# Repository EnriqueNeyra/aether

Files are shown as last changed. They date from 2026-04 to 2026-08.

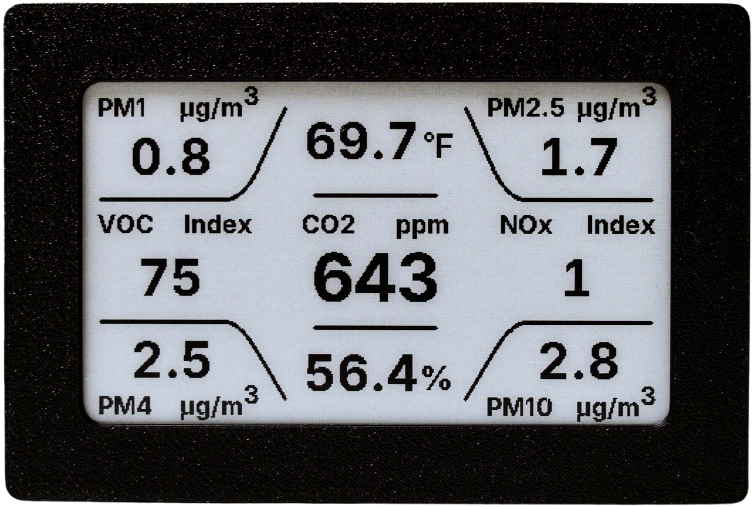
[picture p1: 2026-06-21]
www/assets/aether-device-black.png

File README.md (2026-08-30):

# Aether

A6700222

### Aether is a comprehensive air quality monitor by [**Syntropy Labs**](https://syntropylabs.io/products/aether-air-quality-monitor) built around an ESP32-C3, a Sensirion SEN66 sensor, and a 3.7" e-paper display. It measures **CO2, Temperature, Humidity, PM1.0, PM2.5, PM4.0, PM10, VOC index, and NOx index**, and exposes those readings on-device, on the local network, and through Home Assistant.

## Repo Guide

| Path | Contents |
| --- | --- |
| `firmware/` | ESPHome configuration, custom components, web UI sources, and display code |
| `hardware/pcb/` | KiCad PCB project |
| `hardware/manufacturing/` | PCB manufacturing outputs, BOM, and centroid files |
| `hardware/datasheets/` | Reference datasheets used during hardware design |
| `enclosure/` | SolidWorks enclosure and assembly files |
| `manifests/` | Firmware manifests for OTA and WebUSB |
| `www/` | The combined WebUSB flasher and Quick Start Guide site |

## Contents

- [Features](#features)
- [Hardware](#hardware)
- [Assembly](#assembly)
- [Firmware Setup](#firmware-setup)
  - [Flashing firmware onto a device](#flashing-firmware-onto-a-device)
  - [Firmware development](#firmware-development)
- [Using Aether](#using-aether)
  - [Normal operation](#normal-operation)
  - [Wi-Fi setup and behavior](#wi-fi-setup-and-behavior)
  - [Side button behavior](#side-button-behavior)
  - [Local web UI](#local-web-ui)
  - [Home Assistant & ESPHome API](#home-assistant--esphome-api)
  - [Updates](#pdates)
- [License](#license)

## Features

- Measures CO2, Temperature, Humidity, PM1.0, PM2.5, PM4.0, PM10, VOC index, and NOx index using the **Sensirion SEN66**
- Displays live readings on a **416x240 3.7" e-paper panel**
- Serves a **local web dashboard** from the device itself
- Supports **ESPHome / Home Assistant** integration
- Supports **USB factory flashing**, **firmware recovery**, and **OTA updates**
- Fully local, and can run **with or without Wi-Fi**

## Hardware

To build one Aether unit, the following core parts are needed:

| Part | Link |
| --- | --- |
| **Aether PCB** | [Syntropy Labs Store](https://syntropylabs.io/products/aether-air-quality-monitor-custom-pcb) (PCB files available in [`hardware/`](https://github.com/EnriqueNeyra/aether/tree/main/hardware/manufacturing) folder) |
| **3.7" e-paper display module** | [Good Display](https://buy-lcd.com/products/37-inch-416x240-e-paper-black-and-white-spi-fast-refresh-electronic-eink-display-screen-esl-gdey037t03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) / [Elecrow](https://www.elecrow.com/3-7-inch-240-416-e-paper-display-black-white-e-ink-display-with-spi-communication.html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) |
| **Sensirion SEN66** air quality sensor | [Sensirion](https://sensirion.com/products/catalog/SEN66) |
| **Reverse 6-pin JST-GH cable** | [Adafruit](https://www.adafruit.com/product/5754?srsltid=AfmBOopcC6siE6KqjNqU-nj7AwIrnvlDSqnL19iwFrZ47O6lRIhqRYC8) / [AliExpress](https://www.aliexpress.us/w/wholesale-jst-gh-1.25mm-connector-6-pin-reverse.html?spm=a2g0o.detail.search.0) |
| **3D-printed enclosure parts** | [`enclosure/`](https://github.com/EnriqueNeyra/aether/tree/main/enclosure) |
| **2x M3 x 6 mm countersunk screws + nuts** | [Screws](https://amzn.to/3SKvOgg) / [Nuts](https://amzn.to/44jUIG1) |

<p align="center">A6700230</p>

### Alternative Display Compatibility

The Aether PCB implements the standard 24-pin FPC e-paper interface. While designed for the 3.7" GDEY037T03, it is hardware-compatible with many other common e-paper panels (e.g., those using SSD1680, UC8151D, and IL0373 driver ICs). **Please note that these alternative displays have not yet been tested or confirmed to work with this device.**

If you choose to use an alternative display, you will need to:
1. **Update the firmware** to instantiate the correct `GxEPD2` display driver class.
2. **Modify the enclosure design** to physically fit the new panel dimensions.

For specific supported ICs and detailed firmware instructions, see [display-compatibility.md](display-compatibility.md).

## Assembly

High-level assembly flow:

### 1. Press-fit the SEN66 into the enclosure body.

<p align="center">Insert_SEN66_into_Enclosure</p>

### 2. Connect the e-paper display to the PCB with the FPC connector.

<p align="center">Connect_ePaper_to_PCB</p>

### 3. Press-fit the PCB into the enclosure body.

<p align="center">Insert_PCB_into_Enclosure</p>

### 4. Connect 6-pin JST GH Cable.

<p align="center">Connect_JST_Cable</p>

### 5. Bring display over in position above the PCB.

<p align="center">Display_Placement_1</p>
<p align="center">Display_Placement_2</p>

### 6. Attach the display cover.

<p align="center">Attach_Display_Cover</p>

### 7. Secure the assembly from the bottom with the two M3 fasteners.

<p align="center">Secure_With_M3_Screws</p>

## Firmware Setup
_Any Aether devices purchased through [**Syntropy Labs**](https://syntropylabs.io/) are pre-flashed with device firmware and fully tested_

### Flashing firmware onto a device

#### For a new board or a device that needs recovery:

1. Connect Aether to your computer over USB.
2. Open the [Aether WebUSB flashing tool](https://aether.syntropylabs.io/).
3. Choose **Factory flash (recommended)** for first-time setup or full recovery.
4. Keep the page open until flashing is complete.
5. Let the device boot.

#### For a device that is already set up and just needs newer firmware:

1. Connect the device over USB and open the same flashing page.
2. Choose **Update firmware (OTA)** if you want to preserve the current device settings.

_Note: The flashing page in `www/` is built around **ESP Web Tools / WebUSB** and is intended to work best in **Chrome or Edge**._

### Firmware development

If you are working on the ESPHome firmware:

```sh
git clone https://github.com/EnriqueNeyra/aether.git
cd "aether/firmware"
```

```sh
cd firmware
esphome config aether.yaml
esphome compile aether.yaml
esphome run aether.yaml
```

## Using Aether

### Normal operation

Once powered, Aether reads the SEN66 and refreshes both the on-device display and the local web dashboard. Temperature can be shown in either **Fahrenheit** or **Celsius**.

### Wi-Fi setup and behavior

On boot, Aether will expose a temporary setup access point so you can connect it to Wi-Fi through the captive portal flow. The network will appear as **aether-XXXXX**. 

<p align="center">aether-access-point</p> 

- If you want **local web UI access**, **network-based ota updates**, or **Home Assistant integration**, connect the device to Wi-Fi during setup.
- If you do **not** configure Wi-Fi, the device will still work as a standalone monitor **fully offline**.

Once connected to the access point, you will automatically be redirected to the captive portal. Select your network and enter the password to connect. Once connected to Wi-Fi, the device also hosts its [local web UI](#local-web-ui) at **aether-XXXXXX.local** or the **device's local IP**.

### Side button behavior

The side / boot button supports multiple actions:

- **Short press (tap, under 1 second):** toggles between the normal dashboard and the info screen
- **Long press (hold ~3 seconds) from the normal screen:** enters factory reset confirmation
- **Long press (hold ~3 seconds) again on the reset screen:** confirms the factory reset flow

### Local web UI

When Aether is on your network, it serves a local browser-based dashboard directly from the device. That UI includes:

- A live environment view for sensor readings
- Temperature unit switching
- Firmware version and update status
- A way to trigger firmware updates from the device UI

### Home Assistant & ESPHome API

Because Aether runs ESPHome, it features a native API over Wi-Fi. This allows for:

- **Automatic Home Assistant Integration:** Aether will automatically appear in Home Assistant integrations dashboard once connected to your network. It securely exposes all 9 sensor metrics (CO2, Temp, PM2.5, etc).

<p align="center">
  <a href="https://my.home-assistant.io/redirect/integrations/">
    
  </a>
</p>

- **Custom Integrations:** You can integrate Aether into your own software or scripts using its local HTTP API. Exposed endpoints include:
  - `GET /api/state` - Returns a JSON object with all current sensor metrics and device status.
  - `POST /api/temp_unit?unit=C|F` - Changes the preferred temperature unit.
  - `POST /api/perform_update` - Triggers the device to immediately begin downloading and installing the latest firmware update over HTTP (if one is available).

### Updates

Aether supports more than one update path:

- **Local USB flashing** through the [WebUSB flashing tool](https://aether.syntropylabs.io/) (source located in `www/`)
- **In-device update flow** through the local web UI
- **Home Assistant** when the device is online

Use the USB flashing page for first-time setup and recovery. Use the local web UI for routine updates on devices that are already deployed.

## License

This project (hardware, design files, and firmware) is licensed under the
[Creative Commons Attribution-NonCommercial-ShareAlike 4.0 International License](http://creativecommons.org/licenses/by-nc-sa/4.0/).



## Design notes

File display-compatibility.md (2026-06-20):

# E-Paper Display Compatibility

The Aether project is designed around the **GDEY037T03** (3.7" 416x240) black-and-white e-paper display, which uses the **UC8253** driver IC. 

However, both the hardware (PCB) and software (firmware) are highly adaptable to other e-paper displays.

## Hardware Compatibility (The 24-Pin Standard)

The Aether PCB implements the **standard 24-pin FPC (0.5mm pitch) e-paper interface**. This is the industry standard for small-to-medium raw e-ink panels from manufacturers like Good Display and Waveshare.

Because of this standard, the custom PCB is **hardware-compatible** with a wide variety of other e-paper driver ICs. The external boost circuit on the board (MOSFET, inductor, and schottky diode) that generates the panel's internal driving voltages is universally shared across these controller families.

**Note: While the hardware standard and firmware library theoretically support the ICs listed below, they have not yet been explicitly tested or confirmed to work with the Aether device.**

Other common e-paper driver ICs that use this exact same 24-pin hardware footprint include:

*   **Solomon Systech ICs:**
    *   **SSD1680** (Very common on 2.13", 2.66", and 2.9" panels)
    *   **SSD1677**
    *   **SSD1619**
*   **UltraChip ICs** (Same manufacturer as the UC8253):
    *   **UC8151D / UC8151C** (Common on 1.54" and 2.9" panels)
    *   **UC8159** (Used for 7-color ACeP displays)
    *   **UC8179** (Common on 4.2" panels)
*   **Ilitek ICs:**
    *   **IL0373 / IL0398** (Frequently used for 3-color Black/White/Red panels and some larger B/W screens)

## Software Compatibility (GxEPD2)

While the physical PCB footprint is compatible with all of the ICs listed above, **driver ICs are not natively software-compatible with one another**. Every IC has its own specific command set, memory mapping, and timing waveforms required to drive the e-ink microcapsules.

Fortunately, the Aether firmware uses the `GxEPD2` library, which is the most comprehensive e-paper driver library available for the ESP32. **`GxEPD2` supports all of the ICs listed above.**

### How to Switch Displays in Firmware

To support a display with a different IC, you do not need to rewrite any graphics logic. You only need to update the display class instantiation in the firmware.

Open `firmware/components/aether_epaper/aether_epaper.h`. Currently, it initializes the UC8253:

```cpp
// GDEY037T03 (416x240) using UC8253
static GxEPD2_BW<GxEPD2_370_GDEY037T03, GxEPD2_370_GDEY037T03::HEIGHT>
    display(GxEPD2_370_GDEY037T03(EPD_CS, EPD_DC, EPD_RST, EPD_BUSY));
```

If you were to swap the display to a 2.9" panel using the **SSD1680** IC (e.g., part number GDEY029T94), you would look up its class in the `GxEPD2` documentation and update those lines:

```cpp
// GDEY029T94 (296x128) using SSD1680
static GxEPD2_BW<GxEPD2_290_GDEY029T94, GxEPD2_290_GDEY029T94::HEIGHT>
    display(GxEPD2_290_GDEY029T94(EPD_CS, EPD_DC, EPD_RST, EPD_BUSY));
```

Because `GxEPD2` extends the standard Adafruit GFX library, all existing drawing commands (`display.print`, `display.drawRect`, etc.) will continue to work perfectly. 

*(Note: Depending on the resolution of the new display, you may need to adjust the UI layout coordinates in `aether_epaper_layout.h` to fit the new screen dimensions).*

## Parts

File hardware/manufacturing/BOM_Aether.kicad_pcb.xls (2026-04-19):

Designator | Quantity | Value | Footprint | Package | MPN | DNP | Mount_Type | Description | LCSC Part | Supplier | Manufacturer | MF | MAXIMUM_PACKAGE_HEIGHT | Price | Check_prices | STANDARD | PARTREV | SnapEDA_Link | MP | Description_1 | Availability | MANUFACTURER
C1 | 1 | 10uf/25V | C_0603_1608Metric |  |  |  | smt | Unpolarized capacitor
C10, C11, C12, C13, C14, C16, C19, C20, C8 | 9 | 4.7uf/25V | C_0603_1608Metric |  |  |  | smt | Unpolarized capacitor
C15, C17, C18, C21, C4 | 5 | 1uf/50V | C_0603_1608Metric |  |  |  | smt | Unpolarized capacitor
C2, C3, C5, C9 | 4 | 0.1uf/50V | C_0603_1608Metric |  |  |  | smt | Unpolarized capacitor
C6, C7 | 2 | 22uf/10V | C_0603_1608Metric |  |  |  | smt | Unpolarized capacitor
CN1 | 1 | SH-GH1.25-6PWB | SW-SMD_SH-GH1.25-6PWB |  |  |  | smt | Connector Header 6 position 1.25mm Pitch 1A Surface Mount, Right Angle -25℃~+85℃ | C42372473 | LCSC | SHOU HAN
D1 | 1 | 1N5819WS | D_SOD-323 |  |  |  | smt | 40V 600mV@1A 1A SOD-323 Schottky Barrier Diodes, SOD-323
D2, D3, D4 | 3 | LESD5D5.0CT1G_C5274290 | SOD-523_L1.2-W0.8-LS1.6-BI |  |  |  | smt | 18.6V 150W@8/20us 5V SOD-523 TVS Diodes RoHS | C5274290 | LCSC | LRC
D5, D6, D7 | 3 | MBR0530 | D_SOD-123 |  |  |  | smt | 30V 0.5A Schottky Power Rectifier Diode, SOD-123
FPC1 | 1 | FPC-05FB-24PH20 | FPC-SMD_24P-P0.50_FPC-05FB-24PH20 |  |  |  | smt | FFC/FPC Connector 24 Position 0.5mm Pitch Double-Sided Contacts, Top and Bottom Entry Surface Mount, Right Angle -25℃~+85℃ | C2856831 | LCSC | XUNPU
L1 | 1 | NR3015S2R2MT | IND-SMD_L3.0-W3.0_NR3010 |  |  |  | smt | 1.6A 2.2uH 64mΩ 1.6A ±20% SMD,3x3mm Fixed Inductors RoHS | C42370319 | LCSC | Magnetsyc
L2 | 1 | 10uH/1A | L_1210_3225Metric |  |  |  | smt | Inductor
Q1 | 1 | Si1308EDL | SOT-323_SC-70 |  |  |  | smt | 30V Vds, 1.4A Id, N-Channel MOSFET, SC-70
R1, R10, R12, R2, R3, R6, R9 | 7 | 10k | R_0402_1005Metric |  |  |  | smt | Resistor
R11 | 1 | 3 | R_0402_1005Metric |  |  |  | smt | Resistor
R13 | 1 | 0.47 | R_0402_1005Metric |  |  |  | smt | Resistor
R4, R5 | 2 | 5.1k | R_0402_1005Metric |  |  |  | smt | Resistor
R7 | 1 | 453k | R_0603_1608Metric |  |  |  | smt | Resistor
R8 | 1 | 100k | R_0603_1608Metric |  |  |  | smt | Resistor
SW2 | 1 | TS-1088-AR02016 | SW-SMD_L3.9-W3.0-P4.45 |  |  |  | smt | Tactile Switch SPST 160gf 2mm SMD (SMT) Tab 4mm x 3mm Surface Mount | C720477 | LCSC | XUNPU
SW3 | 1 | TS36XL-6.0 180GF 072 | SW-TH_SHOU-HAN_TS36XL-6.0 |  |  |  | tht | Tactile Switch SPST 180gf 6mm SMD (SMT) Tab 4.55mm Surface Mount, Right Angle | C2859427 | LCSC | SHOU HAN
TP1 | 1 | TestPoint | TestPoint_Pad_D1.5mm |  |  | Yes | smt | test point
TP2 | 1 | TestPoint | TestPoint_Pad_D1.5mm |  |  | Yes | smt | test point
TP3 | 1 | TestPoint | TestPoint_Pad_D1.5mm |  |  | Yes | smt | test point
TP4 | 1 | TestPoint | TestPoint_Pad_D1.5mm |  |  | Yes | smt | test point
TP5 | 1 | TestPoint | TestPoint_Pad_D1.5mm |  |  | Yes | smt | test point
TP6 | 1 | TestPoint | TestPoint_Pad_D1.5mm |  |  | Yes | smt | test point
U1 | 1 | TYPE-C 16PLT-H10.0 | TYPE-C-SMD_USB4120-03-C |  |  |  | smt | USB-C (USB TYPE-C) Receptacle Connector 16 Position Surface Mount | C3151749 | LCSC | SHOU HAN
U2 | 1 | ESP32-C3-MINI-1-N4 | XCVR_ESP32-C3-MINI-1-N4 | SMD-53 Espressif Systems |  |  | smt |  |  |  |  | Espressif Systems | 2.55mm | None | https://www.snapeda.com/parts/ESP32-C3-MINI-1-N4/Espressif+Systems/view-part/?ref=eda | Manufacturer Recommendations | v1.0 | https://www.snapeda.com/parts/ESP32-C3-MINI-1-N4/Espressif+Systems/view-part/?ref=snap | ESP32-C3-MINI-1-N4 | Bluetooth, WiFi 802.11b/g/n, Bluetooth v5.0 Transceiver Module 2.412GHz ~ 2.484GHz PCB Trace Surface Mount | In Stock | Espressif Systems
U3 | 1 | TLV62569DBVR | SOT-23-5_L3.0-W1.7-P0.95-LS2.8-BR |  |  |  | smt | 1.5MHz Buck Adjustable 600mV~5.5V 2A SOT-23-5 Voltage Regulators - DC DC Switching Regulators RoHS | C141836 | LCSC | TI

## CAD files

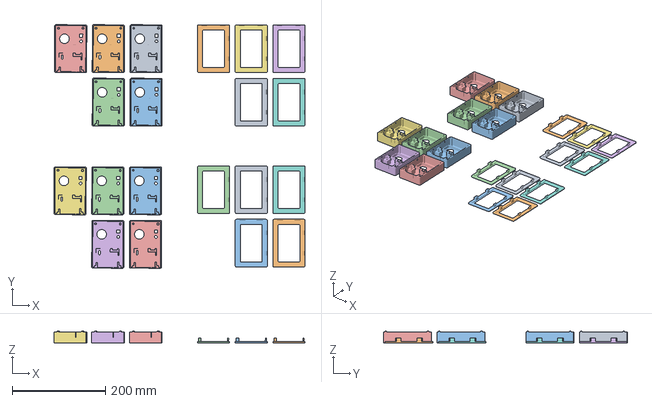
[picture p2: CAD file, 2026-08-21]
enclosure/aether_bulk_print.3mf
539.6 x 523.7 x 25.8 mm
enclosure_body.STEP x 10
display_cover.STEP x 10

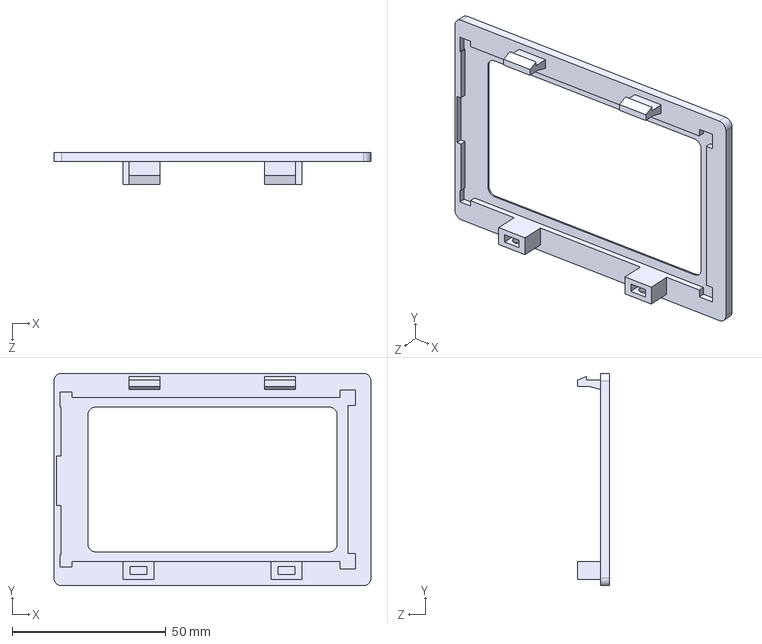
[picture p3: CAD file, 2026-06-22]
enclosure/display_cover.STEP
103.0 x 69.0 x 10.5 mm

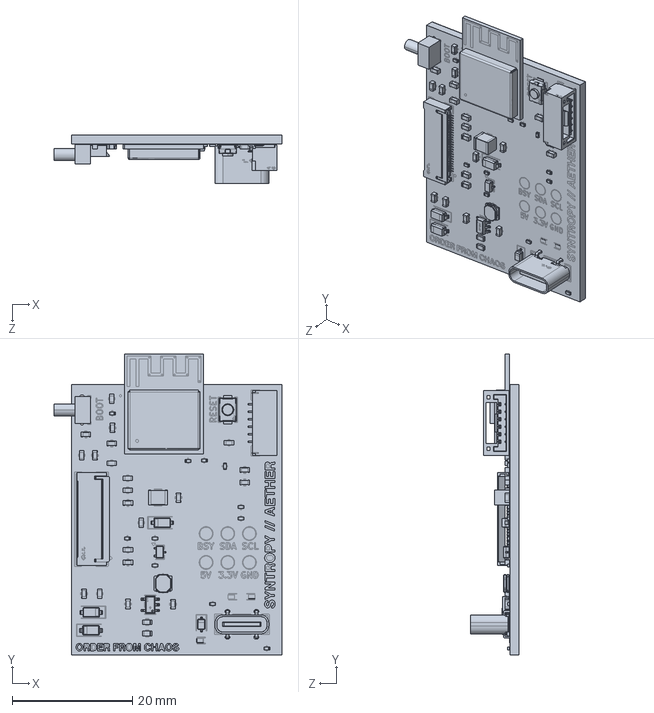
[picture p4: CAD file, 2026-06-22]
enclosure/solidworks/aether_pcb.SLDPRT
37.9 x 50.1 x 8.14 mm

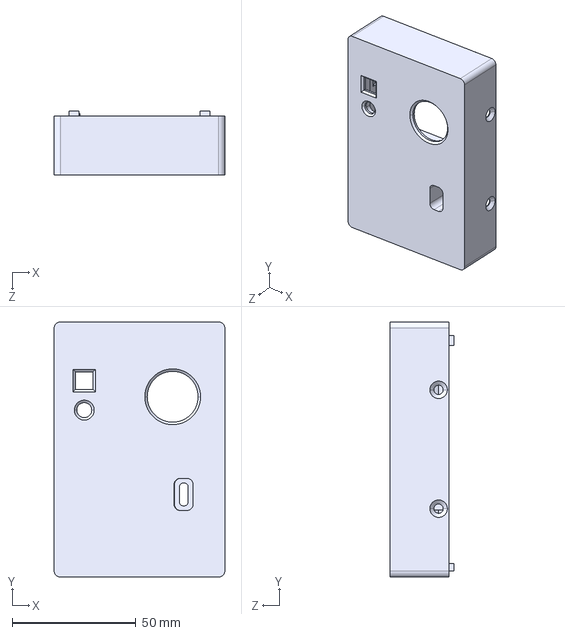
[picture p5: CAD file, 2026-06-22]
enclosure/enclosure_body.STEP
69.0 x 103.0 x 25.8 mm

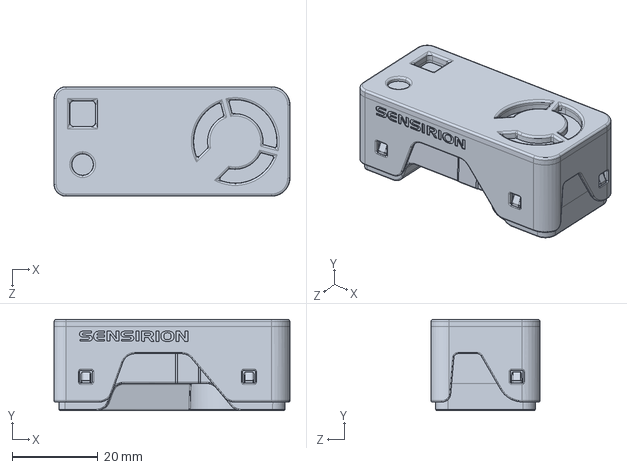
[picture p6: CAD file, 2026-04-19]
enclosure/solidworks/sen66.SLDPRT
55.2 x 21.3 x 25.6 mm

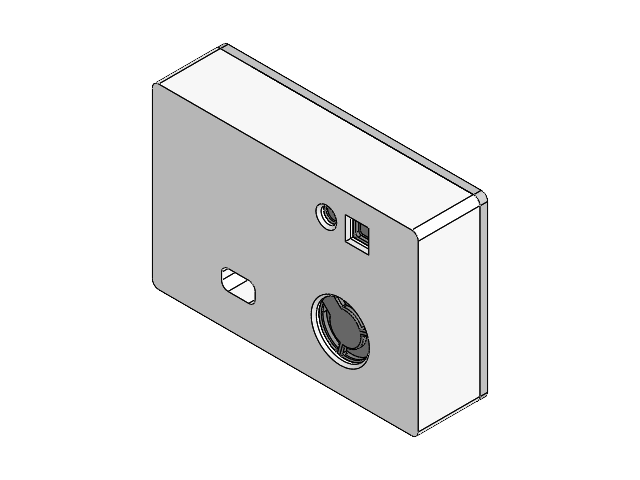
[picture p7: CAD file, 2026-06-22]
enclosure/solidworks/aether_assembly.SLDASM
aether_pcb
SEN66
Enclosure Body
Display Cover

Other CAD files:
enclosure/solidworks/display_module.SLDPRT
enclosure/solidworks/display_cover.SLDPRT
enclosure/solidworks/enclosure_body.SLDPRT

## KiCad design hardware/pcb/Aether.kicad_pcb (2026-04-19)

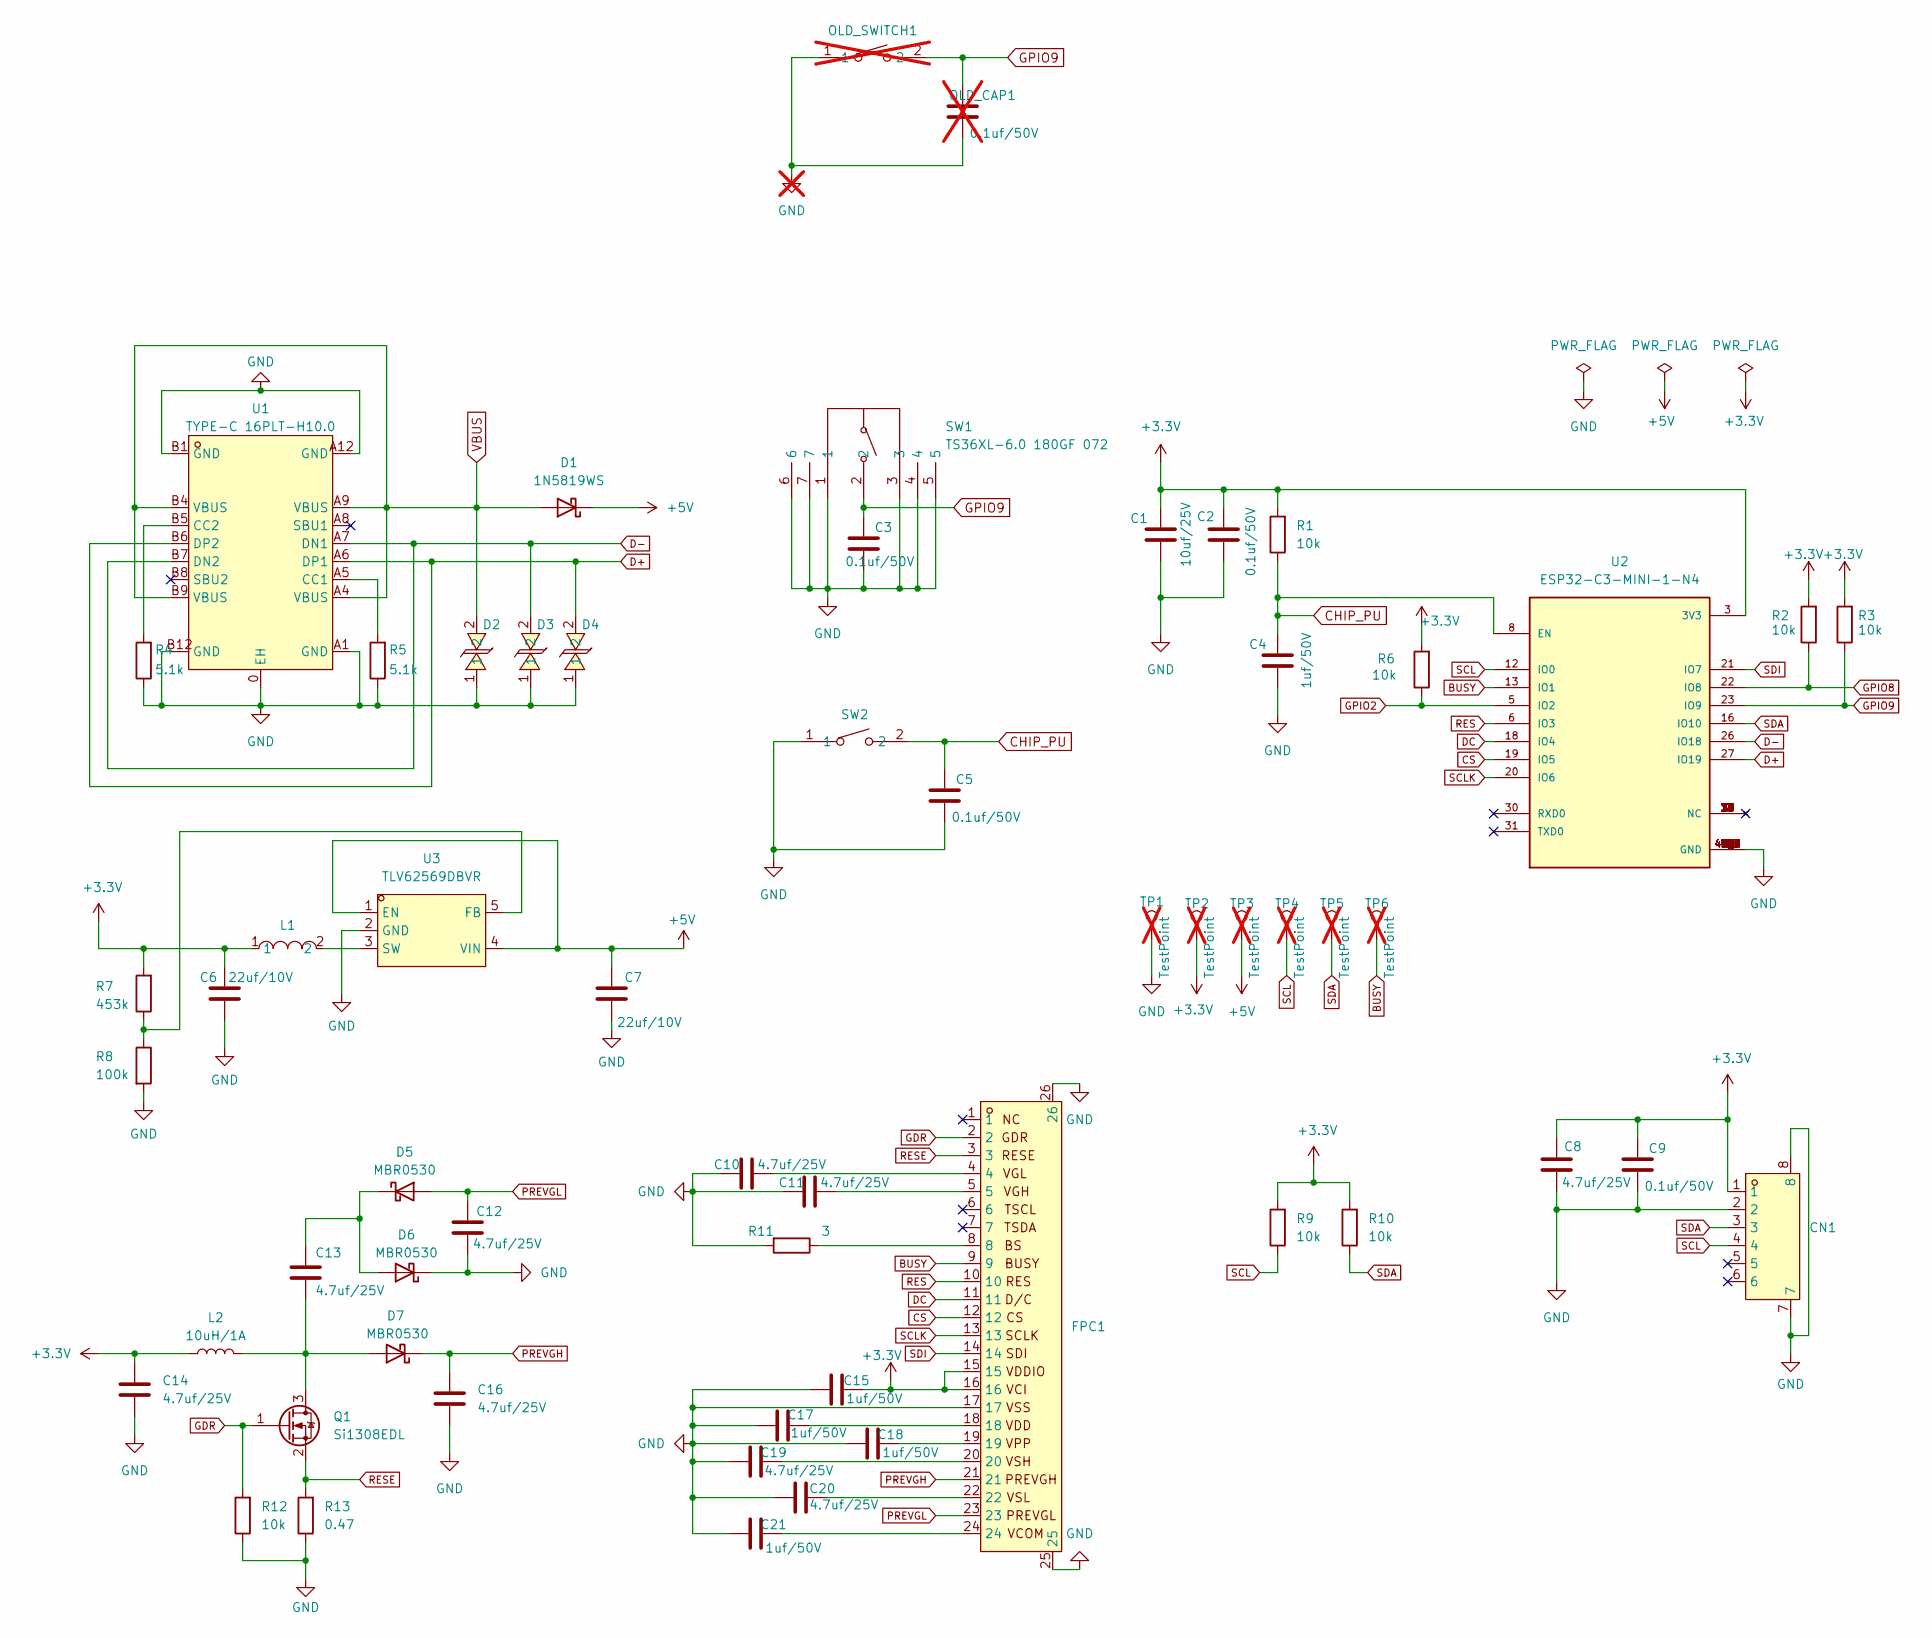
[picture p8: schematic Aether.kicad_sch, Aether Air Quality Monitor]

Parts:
C1: 10uf/25V; C_0603_1608Metric
C2, C3, C5, C9: 0.1uf/50V; C_0603_1608Metric
C4, C15, C17, C18, C21: 1uf/50V; C_0603_1608Metric
C6, C7: 22uf/10V; C_0603_1608Metric
C8, C10, C11, C12, C13, C14, C16, C19, C20: 4.7uf/25V; C_0603_1608Metric
CN1: SH-GH1.25-6PWB; SW-SMD_SH-GH1.25-6PWB; LCSC Part C42372473
D1: 1N5819WS; D_SOD-323
D2, D3, D4: LESD5D5.0CT1G_C5274290; SOD-523_L1.2-W0.8-LS1.6-BI; LCSC Part C5274290
D5, D6, D7: MBR0530; D_SOD-123
FPC1: FPC-05FB-24PH20; FPC-SMD_24P-P0.50_FPC-05FB-24PH20; LCSC Part C2856831
L1: NR3015S2R2MT; IND-SMD_L3.0-W3.0_NR3010; LCSC Part C42370319
L2: 10uH/1A; L_1210_3225Metric
OLD_CAP1: 0.1uf/50V; C_0603_1608Metric; not fitted
OLD_SWITCH1: TS-1088-AR02016; SW-SMD_L3.9-W3.0-P4.45; LCSC Part C720477; not fitted
Q1: Si1308EDL; SOT-323_SC-70
R1, R2, R3, R6, R9, R10, R12: 10k; R_0402_1005Metric
R4, R5: 5.1k; R_0402_1005Metric
R7: 453k; R_0603_1608Metric
R8: 100k; R_0603_1608Metric
R11: 3; R_0402_1005Metric
R13: 0.47; R_0402_1005Metric
SW1: TS36XL-6.0 180GF 072; SW-TH_SHOU-HAN_TS36XL-6.0; LCSC Part C2859427
SW2: TS-1088-AR02016; SW-SMD_L3.9-W3.0-P4.45; LCSC Part C720477
TP1, TP2, TP3, TP4, TP5, TP6: TestPoint; TestPoint_Pad_D1.5mm; not fitted
U1: TYPE-C 16PLT-H10.0; TYPE-C-SMD_USB4120-03-C; LCSC Part C3151749
U2: ESP32-C3-MINI-1-N4; XCVR_ESP32-C3-MINI-1-N4; PARTREV v1.0
U3: TLV62569DBVR; SOT-23-5_L3.0-W1.7-P0.95-LS2.8-BR; LCSC Part C141836

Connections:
+3.3V: C1.2, C2.1, C6.2, C8.2, C9.1, C14.1, C15.2, CN1.1, FPC1.15, FPC1.16, L1.1, L2.1, R1.2, R2.2, R3.2, R6.2, R7.2, R9.2, R10.2, TP2.1, U2.3 (3V3)
+5V: C7.1, D1.1 (K), TP3.1, U3.1 (EN), U3.4 (VIN)
BUSY: FPC1.9, TP6.1, U2.13 (IO1)
CHIP_PU: C4.2, C5.1, R1.1, SW2.2, U2.8 (EN)
CS: FPC1.12, U2.19 (IO5)
D+: D4.2, U1.A6 (DP1), U1.B6 (DP2), U2.27 (IO19)
D-: D3.2, U1.A7 (DN1), U1.B7 (DN2), U2.26 (IO18)
DC: FPC1.11, U2.18 (IO4)
GDR: FPC1.2, Q1.1 (G), R12.2
GND: C1.1, C2.2, C3.2, C4.1, C5.2, C6.1, C7.2, C8.1, C9.2, C10.1, C11.1, C12.2, C14.2, C15.1, C16.2, C17.2, C18.2, C19.1, C20.1, C21.1, CN1.2, CN1.7, CN1.8, D2.1, D3.1, D4.1, D6.1 (K), FPC1.17, FPC1.25, FPC1.26, OLD_CAP1.2, OLD_SWITCH1.1, R4.1, R5.1, R8.2, R11.2, R12.1, R13.1, SW1.1, SW1.3, SW1.4, SW1.5, SW1.6, SW1.7, SW2.1, TP1.1, U1.0 (EH), U1.A1 (GND), U1.A12 (GND), U1.B1 (GND), U1.B12 (GND), U2.1 (GND), U2.2 (GND), U2.11 (GND), U2.14 (GND), U2.36 (GND), U2.37 (GND), U2.38 (GND), U2.39 (GND), U2.40 (GND), U2.41 (GND), U2.42 (GND), U2.43 (GND), U2.44 (GND), U2.45 (GND), U2.46 (GND), U2.47 (GND), U2.48 (GND), U2.49_1 (GND), U2.49_2 (GND), U2.49_3 (GND), U2.49_4 (GND), U2.49_5 (GND), U2.49_6 (GND), U2.49_7 (GND), U2.49_8 (GND), U2.49_9 (GND), U2.50 (GND), U2.51 (GND), U2.52 (GND), U2.53 (GND), U3.2 (GND)
GPIO2: R6.1, U2.5 (IO2)
GPIO8: R2.1, U2.22 (IO8)
GPIO9: C3.1, OLD_CAP1.1, OLD_SWITCH1.2, R3.1, SW1.2, U2.23 (IO9)
unnamed: C10.2, FPC1.4
unnamed: C11.2, FPC1.5
unnamed: C17.1, FPC1.18
unnamed: C18.1, FPC1.19
unnamed: C19.2, FPC1.20
unnamed: C20.2, FPC1.22
unnamed: C21.2, FPC1.24
unnamed: C13.1, D5.1 (K), D6.2 (A)
unnamed: C13.2, D7.2 (A), L2.2, Q1.3 (D)
unnamed: FPC1.8, R11.1
unnamed: R5.2, U1.A5 (CC1)
unnamed: R4.2, U1.B5 (CC2)
unnamed: R7.1, R8.1, U3.5 (FB)
unnamed: L1.2, U3.3 (SW)
PREVGH: C16.1, D7.1 (K), FPC1.21
PREVGL: C12.1, D5.2 (A), FPC1.23
RES: FPC1.10, U2.6 (IO3)
RESE: FPC1.3, Q1.2 (S), R13.2
SCL: CN1.4, R9.1, TP4.1, U2.12 (IO0)
SCLK: FPC1.13, U2.20 (IO6)
SDA: CN1.3, R10.1, TP5.1, U2.16 (IO10)
SDI: FPC1.14, U2.21 (IO7)
VBUS: D1.2 (A), D2.2, U1.A4 (VBUS), U1.A9 (VBUS), U1.B4 (VBUS), U1.B9 (VBUS)

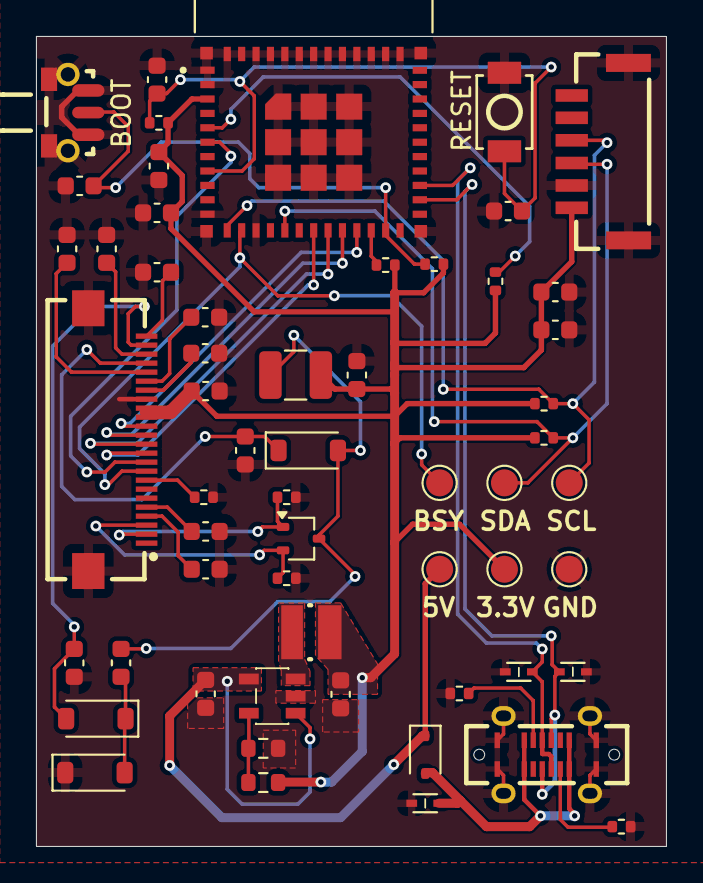
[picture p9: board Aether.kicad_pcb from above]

Board: 2 copper layers, 35.0 x 45.0 mm, 57 parts (0 on the bottom side), 36 nets.

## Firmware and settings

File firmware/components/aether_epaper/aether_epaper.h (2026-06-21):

#pragma once

#include <Arduino.h>
#include <GxEPD2_BW.h>
#include <SPI.h>
#include <Wire.h>
#include <cmath>
#include <cstring>
#include <string>
#include <qrcode.h>

// ESPHome includes
#include "esphome/core/application.h"
#include "esphome/components/wifi/wifi_component.h"

// Layout and Fonts
#include "Inter_Bold12pt7b.h"
#include "Inter_Bold18pt7b.h"
#include "Inter_Bold9pt7b.h"
#include "Inter_Bold_Tabular18pt7b.h"
#include "Inter_Bold_Tabular24pt7b.h"
#include "Inter_ExtraBold_Device_Information_Subset18pt7b.h"
#include "Inter_ExtraBold_Factory_Reset_Subset20pt7b.h"
#include "Satoshi_800_Logo_Subset22pt7b.h"
#include "aether_epaper_layout.h"

namespace aether
{

  namespace aether_epaper
  {

// ==== SPI + Display Pin Configuration ====
#define EPD_MOSI 7
#define EPD_SCK 6
#define EPD_CS 5
#define EPD_DC 4
#define EPD_RST 3
#define EPD_BUSY 1

    // GDEY037T03 (416x240)
    static GxEPD2_BW<GxEPD2_370_GDEY037T03, GxEPD2_370_GDEY037T03::HEIGHT>
        display(GxEPD2_370_GDEY037T03(EPD_CS, EPD_DC, EPD_RST, EPD_BUSY));

    // --- State ---
    enum DisplayMode
    {
      MODE_BOOT,
      MODE_NORMAL,
      MODE_INFO,
      MODE_RESET
    };

    static bool s_inited = false;
    static DisplayMode g_display_mode = MODE_BOOT;
    static bool g_use_f = false;
    static uint8_t g_boot_full_refreshes = 0;
    static uint8_t g_boot_frame = 0;
    static int8_t g_last_info_wifi_state = -1;
    static unsigned long g_last_normal_render_ms = 0;
    static unsigned long g_last_boot_frame_ms = 0;
    static unsigned long g_boot_start_ms = 0;

    // --- Cached Layout Data ---
    struct BootWordmarkLayout
    {
      int baseline_y, left_x, slash_1_x, slash_2_x, right_x;
    };
    static BootWordmarkLayout g_boot_layout = {0, 0, 0, 0, 0};

    // --- Cached readings (stored in °C internally) ---
    static float g_co2 = NAN, g_temp = NAN, g_rh = NAN;
    static float g_pm1 = NAN, g_pm25 = NAN, g_pm4 = NAN, g_pm10 = NAN;
    static float g_voc = NAN, g_nox = NAN;

    // --- Config ---
    static constexpr unsigned long NORMAL_REFRESH_MS = 5000;
    static constexpr unsigned long BOOT_FRAME_MS = 500;
    static constexpr uint8_t BOOT_SLASH_FRAME_COUNT = 4;
    static constexpr unsigned long BOOT_TIMEOUT_MS = 75000;
    static constexpr const char *INFO_INSTRUCTIONS_URL = "https://aether.syntropylabs.io/";

    inline void draw_info_qr_card(int x, int y, const char *target);
    inline void draw_info_qr_card(int x, int y, const char *target,
                                  int scale, int padding);
    inline void draw_connected_info_bracket(bool left_side);

    // --- Paged Rendering Helper ---
    template <typename F>
    inline void render_paged(bool full_refresh, F &&draw_func)
    {
      if (full_refresh)
        display.setFullWindow();
      else
        display.setPartialWindow(0, 0, display.width(), display.height());

      display.firstPage();
      do
      {
        draw_func();
        esphome::App.feed_wdt();
      } while (display.nextPage());
    }

    // --- Initialization & Validation ---
    inline void init_once()
    {
      if (s_inited)
        return;

      pinMode(EPD_CS, OUTPUT);
      pinMode(EPD_DC, OUTPUT);
      pinMode(EPD_RST, OUTPUT);
      pinMode(EPD_BUSY, INPUT);

      SPI.begin(EPD_SCK, -1, EPD_MOSI);
      display.init(115200, true, 2, false);
      display.setRotation(1);

      // Calculate boot layout once
      display.setFont(&Satoshi_800_subset22pt7b);
      int16_t x1, y1;
      uint16_t w, h;
      display.getTextBounds("Syntropy // Labs", 0, 0, &x1, &y1, &w, &h);
      int baseline_y = display.height() / 2 - y1 - static_cast<int>(h) / 2;

      auto text_adv = [](const char *text)
      {
        int adv = 0;
        for (const char *p = text; p && *p; ++p)
          adv += Satoshi_800_subset22pt7b.glyph[*p - Satoshi_800_subset22pt7b.first].xAdvance;
        return adv;
      };

      int left_adv = text_adv("Syntropy ");
      int slash_adv = Satoshi_800_subset22pt7b.glyph['/' - Satoshi_800_subset22pt7b.first].xAdvance;
      int right_adv = text_adv(" Labs");
      int total_w = left_adv + (slash_adv * 2) + right_adv;

      int left_x = display.width() / 2 - total_w / 2;
      g_boot_layout = {baseline_y, left_x, left_x + left_adv, left_x + left_adv + slash_adv, left_x + left_adv + (slash_adv * 2)};

      s_inited = true;
    }

    inline bool all_metrics_ready()
    {
      return aether_epaper_layout::has_real_value(g_co2) &&
             aether_epaper_layout::has_real_value(g_temp) &&
             aether_epaper_layout::has_real_value(g_rh) &&
             aether_epaper_layout::has_real_value(g_pm1) &&
             aether_epaper_layout::has_real_value(g_pm25) &&
             aether_epaper_layout::has_real_value(g_pm4) &&
             aether_epaper_layout::has_real_value(g_pm10) &&
             aether_epaper_layout::has_real_value(g_voc) &&
             aether_epaper_layout::has_real_value(g_nox);
    }

    inline void draw_boot_content(uint8_t frame)
    {
      display.setTextColor(GxEPD_BLACK);
      aether_epaper_layout::print_left(display, g_boot_layout.left_x, g_boot_layout.baseline_y, &Satoshi_800_subset22pt7b, "Syntropy ");

      static constexpr const char *SLASHES[4] = {"//", " /", "  ", "/ "};
      const char *s = SLASHES[frame % 4];
      if (s[0] == '/')
        aether_epaper_layout::print_left(display, g_boot_layout.slash_1_x, g_boot_layout.baseline_y, &Satoshi_800_subset22pt7b, "/");
      if (s[1] == '/')
        aether_epaper_layout::print_left(display, g_boot_layout.slash_2_x, g_boot_layout.baseline_y, &Satoshi_800_subset22pt7b, "/");

      aether_epaper_layout::print_left(display, g_boot_layout.right_x, g_boot_layout.baseline_y, &Satoshi_800_subset22pt7b, " Labs");
    }

    // --- High-Level Renderers ---
    inline void render_boot(uint8_t frame, bool full)
    {
      if (full)
      {
        render_paged(true, [frame]()
                     {
          display.fillScreen(GxEPD_WHITE);
          draw_boot_content(frame); });
      }
      else
      {
        int px = g_boot_layout.slash_1_x - 12, py = g_boot_layout.baseline_y - 40;
        int pw = (g_boot_layout.right_x - g_boot_layout.slash_1_x) + 24, ph = 60;

        display.setPartialWindow(px, py, pw, ph);
        display.firstPage();
        do
        {
          display.fillRect(px, py, pw, ph, GxEPD_WHITE);
          static constexpr const char *SLASHES[4] = {"//", " /", "  ", "/ "};
          const char *s = SLASHES[frame % 4];
          display.setTextColor(GxEPD_BLACK);
          if (s[0] == '/')
            aether_epaper_layout::print_left(display, g_boot_layout.slash_1_x, g_boot_layout.baseline_y, &Satoshi_800_subset22pt7b, "/");
          if (s[1] == '/')
            aether_epaper_layout::print_left(display, g_boot_layout.slash_2_x, g_boot_layout.baseline_y, &Satoshi_800_subset22pt7b, "/");
          esphome::App.feed_wdt();
        } while (display.nextPage());
      }
    }
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

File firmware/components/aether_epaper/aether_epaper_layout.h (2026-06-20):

#pragma once

#include <algorithm>
#include <cmath>
#include <cstdio>
#include <cstring>

extern const GFXfont Inter_Bold9pt7b;
extern const GFXfont Inter_Bold12pt7b;
extern const GFXfont Inter_Bold18pt7b;
extern const GFXfont Inter_Bold_Tabular18pt7b;
extern const GFXfont Inter_Bold_Tabular24pt7b;
extern const GFXfont Inter_ExtraBold_Device_Information_Subset18pt7b;

namespace aether
{

  namespace aether_epaper_layout
  {

    struct Metrics
    {
      float co2 = NAN, temp_c = NAN, rh = NAN;
      float pm1 = NAN, pm25 = NAN, pm4 = NAN, pm10 = NAN;
      float voc = NAN, nox = NAN;
    };

    struct Point { int x, y; };

    static constexpr const GFXfont *kSmallLabelFont = &Inter_Bold9pt7b;
    static constexpr const GFXfont *kCenterMinorValueFont = &Inter_Bold_Tabular18pt7b;
    static constexpr const GFXfont *kTempSuffixFont = &Inter_Bold12pt7b;
    template <typename Display>
    inline void draw_caution_icon(Display &display, int cx, int cy, int size)
    {
      int x = cx - size / 2;
      int y = cy - size / 2;
      
      // 1. Draw a filled black diamond
      display.fillTriangle(cx, y, x + size, cy, x, cy, GxEPD_BLACK);
      display.fillTriangle(cx, y + size, x + size, cy, x, cy, GxEPD_BLACK);
      
      // 2. Draw a white diamond inside (3px border thickness ~2.1px visually)
      int b = 3; 
      display.fillTriangle(cx, y + b, x + size - b, cy, x + b, cy, GxEPD_WHITE);
      display.fillTriangle(cx, y + size - b, x + size - b, cy, x + b, cy, GxEPD_WHITE);
      
      // 3. Draw manual exclamation mark perfectly centered vertically
      int stem_w = 2;
      int stem_h = size / 3 + 1; 
      int dot_size = 2;
      int gap = 2;
      int total_h = stem_h + gap + dot_size;
      
      int stem_y = cy - total_h / 2;
      display.fillRect(cx - 1, stem_y, stem_w, stem_h, GxEPD_BLACK);
      display.fillRect(cx - 1, stem_y + stem_h + gap, dot_size, dot_size, GxEPD_BLACK);
    }

    inline bool has_real_value(float value) { return std::isfinite(value); }

    template <typename Display>
    inline void measure_text(Display &display, const GFXfont *font, const char *text,
                             int16_t &x1, int16_t &y1, uint16_t &w, uint16_t &h)
    {
      display.setFont(font);
      display.getTextBounds(text, 0, 0, &x1, &y1, &w, &h);
    }

    template <typename Display>
    inline int text_width(Display &display, const GFXfont *font, const char *text)
    {
      int16_t x1, y1; uint16_t w, h;
      measure_text(display, font, text, x1, y1, w, h);
      return static_cast<int>(w);
    }

    template <typename Display>
    inline int text_height(Display &display, const GFXfont *font, const char *text)
    {
      int16_t x1, y1; uint16_t w, h;
      measure_text(display, font, text, x1, y1, w, h);
      return static_cast<int>(h);
    }

    template <typename Display>
    inline int top_aligned_baseline(Display &display, const GFXfont *font,
                                    const char *text, int top)
    {
      int16_t x1, y1; uint16_t w, h;
      measure_text(display, font, text, x1, y1, w, h);
      return top - y1;
    }

    template <typename Display>
    inline void print_left(Display &display, int x, int y, const GFXfont *font, const char *text)
    {
      display.setFont(font);
      display.setCursor(x, y);
      display.print(text);
    }

    template <typename Display>
    inline void print_centered(Display &display, int x, int y, const GFXfont *font, const char *text)
    {
      int16_t x1, y1; uint16_t w, h;
      measure_text(display, font, text, x1, y1, w, h);
      display.setCursor(x - x1 - static_cast<int>(w) / 2, y);
      display.print(text);
    }

    template <typename Display>
    inline void print_right(Display &display, int right_x, int y, const GFXfont *font, const char *text)
    {
      int16_t x1, y1; uint16_t w, h;
      measure_text(display, font, text, x1, y1, w, h);
      display.setCursor(right_x - x1 - static_cast<int>(w), y);
      display.print(text);
    }

    template <typename Display>
    inline void draw_alert_if_needed(Display &display, const GFXfont *font,
                                     const char *text, int center_x, int baseline_y,
                                     bool alert, int icon_offset = 17, int icon_size = 24)
    {
      if (!alert) return;
      int16_t x1, y1; uint16_t w, h;
      measure_text(display, font, text, x1, y1, w, h);
      int cy = baseline_y + y1 + (int)h / 2;
      draw_caution_icon(display, center_x + (int)w / 2 + icon_offset, cy, icon_size);
    }

    inline void format_metric(char *buf, size_t size, float value, const char *format)
    {
      if (has_real_value(value)) snprintf(buf, size, format, value);
      else snprintf(buf, size, "--");
    }

    inline bool is_digits_subset_text(const char *text)
    {
      if (!text || !*text) return false;
      for (const char *p = text; *p; ++p) if ((*p < '0' || *p > '9') && *p != '.') return false;
      return true;
    }

    inline const GFXfont *metric_value_font(const char *text,
                                             const GFXfont *tabular,
                                             const GFXfont *fallback)
    {
      return is_digits_subset_text(text) ? tabular : fallback;
    }

    template <typename Display>
    inline void stamp_stroke(Display &display, int x, int y, int stroke_radius)
    {
      if (stroke_radius <= 0) { display.fillRect(x, y, 1, 1, GxEPD_BLACK); return; }
      display.fillCircle(x, y, stroke_radius, GxEPD_BLACK);
    }

    template <typename Display>
    inline void draw_stroked_line(Display &display, Point start, Point end, int stroke_radius)
    {
      const float dx = static_cast<float>(end.x - start.x);
      const float dy = static_cast<float>(end.y - start.y);
      const int steps = std::max(std::abs(end.x - start.x), std::abs(end.y - start.y));
      if (steps == 0) { stamp_stroke(display, start.x, start.y, stroke_radius); return; }
      for (int i = 0; i <= steps; ++i) {
        const float t = (float)i / (float)steps;
        stamp_stroke(display, (int)std::lround(start.x + dx * t), (int)std::lround(start.y + dy * t), stroke_radius);
      }
    }

    template <typename Display>
    inline void draw_stroked_quadratic(Display &display, Point start, Point control, Point end, int stroke_radius)
    {
      const int steps = std::max(16, std::max(std::abs(end.x - start.x), std::abs(end.y - start.y)) * 2);
      for (int i = 0; i <= steps; ++i) {
        const float t = (float)i / (float)steps;
        const float mt = 1.0f - t;
        const float x = mt * mt * start.x + 2.0f * mt * t * control.x + t * t * end.x;
        const float y = mt * mt * start.y + 2.0f * mt * t * control.y + t * t * end.y;
        stamp_stroke(display, (int)std::lround(x), (int)std::lround(y), stroke_radius);
      }
    }
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

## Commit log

2026-04-19 - Overhaul display, web UI, and device config - Rewrote e-paper rendering with proper layout system, boot animation, info screen with QR codes, and factory reset flow - Split web UI out of inline C++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
    [aether_display.h]
2026-04-19 Rename aether_display → aether_epaper, aether_ui → aether_web_ui
    Rename component directories, header files, namespaces, class name
    (AetherUI → AetherWebUI), YAML keys, include paths, and all
    references in source code, preview tool, and documentation.
2026-04-19 Populate all current KiCAD and Solidworks files
    [Aether.kicad_pcb, Aether.kicad_sch, BOM_Aether.kicad_pcb.xls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]
2026-06-20 improve pages deplyment and update flow
2026-06-20 Improve local web UI, fix redundant pages release in workflow
    [aether_epaper.h]
2026-06-22 update cad files
    [Display Cover.SLDPRT, Display Module.SLDPRT, Enclosure Body.SLDPRT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]
2026-08-04 Document side button press durations in README
2026-08-21 add 3mf print file [skip release]
    [aether_bulk_print.3mf]
2026-10-26 Keep main building on the latest ESPHome and fix audit findings
    ESPHome 2026.9.0 removed AsyncWebServerRequest::url(), so main no longer
    compiled on the latest release, which release.yml installs on every run.
    Firmware:
    - Read request paths with url_to(); rename esp32_improv to improv_ble.
    - Verify the OTA host's TLS certificate (verify_ssl: true). The manifest
    carries the image MD5, so it has to come from a trusted host.
    - Let the captive portal own "/" while the setup AP portal is active.
    - Make the /api/state truncation check reachable.
    - Select the ESP32 toolchain via a `toolchain` substitution. platformio is
    removed in ESPHome 2027.2.0; esp-idf builds once esphome#21317 ships.
    - De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
2026-10-26 License the firmware under GPLv3; keep CC BY-NC-SA elsewhere
    The firmware is built on GPLv3 code (ESPHome's C++ runtime and GxEPD2),
    so the distributed binaries are GPLv3 combined works and a non-commercial
    restriction can't apply to them. Put firmware/ under GPLv3 and keep CC
    BY-NC-SA 4.0 for hardware, enclosure, site, and docs. The root LICENSE now
    states the per-directory scope; README and AGENTS.md match.
2026-10-27 Fix re-audit findings in firmware, site and CI
    - Remove ESPHome network OTA from the release config; updates come only from
    the official HTTPS manifest or USB. aether-dev.yaml adds it back for
    development flashing.
    - Close web_server firmware uploads (ota: false) and stop exposing internal
    entities.
    - Require a side-button press to authorize Bluetooth Wi-Fi provisioning.
    - Enable keyless API encryption so a client such as Home Assistant can
    provision a key.
    - Debounce the side button, and cancel an unconfirmed factory reset after 30 s.
    - Stop a missing or stuck e-paper panel from boot-looping the device: feed
    the watchdog during BUSY waits, mark the panel faulted after a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
2026-10-27 Load README images from the repo at web size
    The README pulled eleven full-size photos (about 34 MB, mostly 3840x2160)
    from GitHub attachments to show them 700 px wide. Store them in docs/images
    instead, resized to 1400 px (1600 px for the banner) as progressive JPEGs:
    about 750 KB in total. The banner photo is converted from its wide-color
    profile to sRGB so its colors survive without the embedded profile.
    Also give the two camera-named photos descriptive alt text.
2026-10-27 Serve the site's device photo as a web-sized WebP
    The Quick Start page loaded a 1647x1105 PNG (2.9 MB) and showed it at most
    440 px wide. Replace it with an 880 px WebP with transparency (61 KB), and
    give the img width/height so the page doesn't shift while it loads.
2026-10-29 Explain the Home Assistant prompt after a factory reset
    A factory reset clears the device's API key while Home Assistant keeps its
    copy, so Home Assistant reports that the device disabled transport
    encryption. Confirming is correct: Home Assistant reconnects and provisions
    the key it stored again.
2026-10-29 Trim the Quick Start page back to main's text
    Remove the notes this branch added (Bluetooth button press, 10-minute
    setup network, restart-setup-network gesture, 30 s reset cancel, longer
    recovery steps and custom browser-error messages) and restore main's
    wording. Keep the technical changes: self-hosted ESP Web Tools, inline
    icons instead of the unpkg icon library, the WebP device photo, and the
    styled install button. Two wording fixes stay because they match the page:
    "Click Install" for that button, and "Need Help" now names the Install
    Aether firmware button instead of a "Factory flash" option that doesn't
    exist.
